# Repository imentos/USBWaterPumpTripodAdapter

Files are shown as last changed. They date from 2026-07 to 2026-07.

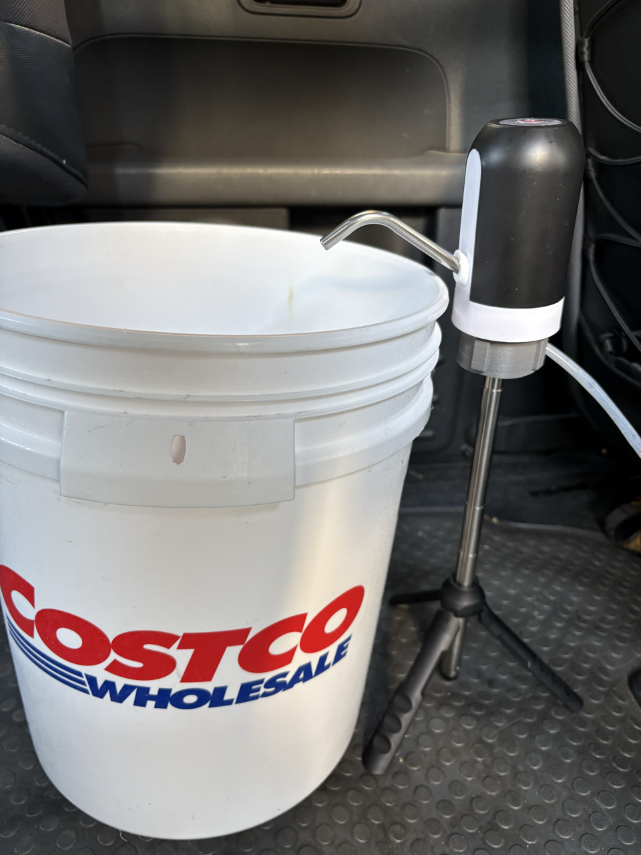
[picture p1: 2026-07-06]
photos/IMG_0860 Large.png

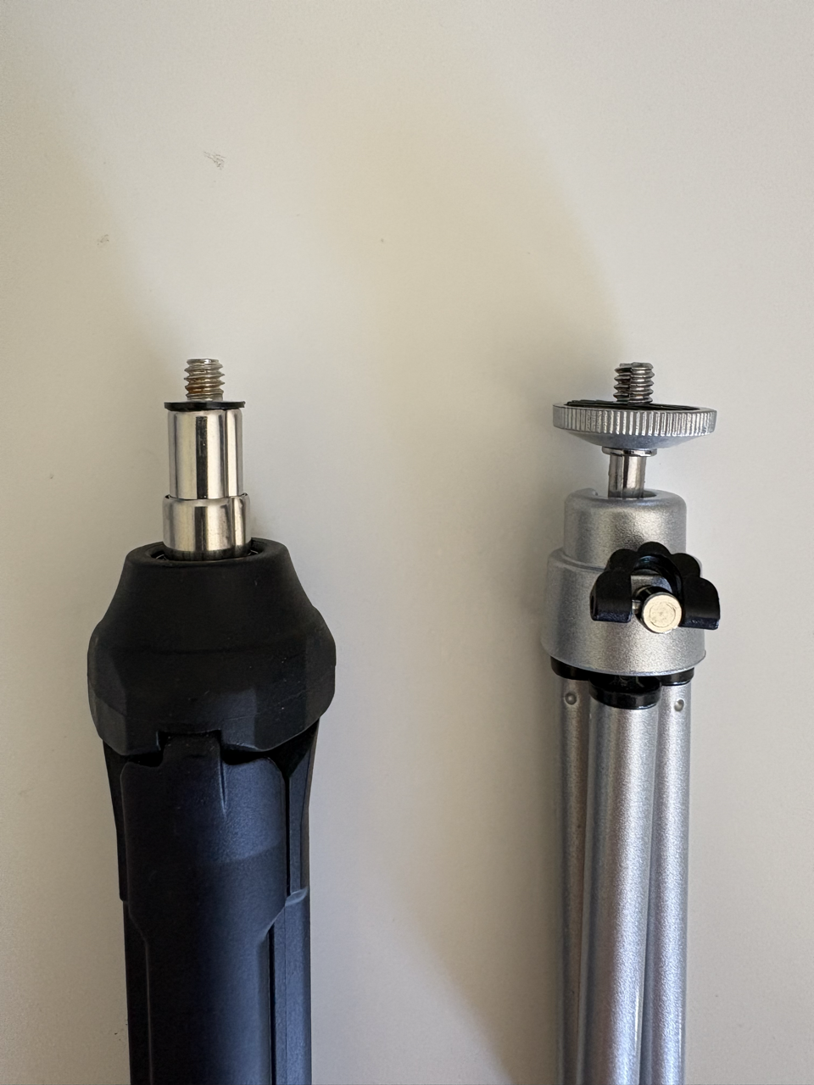
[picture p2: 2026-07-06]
photos/IMG_0835 Large.png

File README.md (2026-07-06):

# USB Water Pump to Tripod Adapter

Three competing FDM-printable concepts for adapting a common USB rechargeable water pump to the photography ecosystem via a standard 1/4"-20 camera mount.

## Shared Assumptions

- Pump bottom has two screws at 32 mm spacing and a center locating cylinder.
- Screw holes are M3 clearance at 3.4 mm.
- Top locating pocket is 18.5 mm diameter by 3.0 mm deep.
- Tripod interface uses a brass 1/4"-20 heat-set insert or metal threaded insert.
- Bottom insert socket assumes 8.2 mm OD by 9.8 mm depth; tune to the actual insert datasheet.
- Print material: PETG or ASA preferred for water resistance; PLA acceptable for fit prototypes.

## Concepts

### Concept A: Low-Profile Round Puck

Smallest and simplest MVP. A 76 mm round adapter with chamfered water-shedding edges, pump screw holes, a top locating pocket, and a reinforced center insert boss.

Best for:
- Fastest iteration
- Easiest print
- Lowest manufacturing complexity

Tradeoff:
- Wider disk than strictly necessary.

### Concept B: Bone Bridge

Material-efficient bridge shape connecting the two pump screw bosses and the center tripod insert boss. Includes side scallops to reduce weight and drying time.

Best for:
- Lower material use
- Distinct product shape
- Keeping strength along the screw-to-insert load path

Tradeoff:
- More exposed edges; less splash shielding than Concept C.

### Concept C: Sealed Tall Boss

Stronger, taller adapter with a pump-foot skirt and shallow groove for silicone or an O-ring style seal. Designed for higher torque from magic arms or cabinet-edge mounts.

Best for:
- Higher load margin
- Better splash resistance
- More confidence with off-axis mounting

Tradeoff:
- Heaviest and slowest to print.

## Print Recommendations

- Orientation: flat on the tripod side, pump side up.
- Layer height: 0.20 mm.
- Perimeters: 4.
- Top/bottom layers: 5.
- Infill: 35% gyroid or cubic.
- Material: PETG for MVP field testing.
- Insert installation: heat-set from bottom after print; use a 1/4"-20 screw as an alignment mandrel while cooling.
- Waterproofing: add thin silicone under pump contact face; avoid sealing screw heads permanently until fit is validated.

## Estimated Print Time and Material

Estimates are based on STL sampled volume, 35% infill, 4 perimeters, 1.24 g/cm3 PETG/PLA density, and a conservative desktop FDM rate. Use a slicer for final numbers.

| Concept | Solid Equivalent | Estimated Printed Mass | Estimated Time |
| --- | ---: | ---: | ---: |
| A Low-Profile Round | 49.3 cm3 | 36-43 g | 2.0-2.7 hr |
| B Bone Bridge | 16.6 cm3 | 14-19 g | 1.1-1.6 hr |
| C Sealed Tall Boss | 68.6 cm3 | 50-60 g | 2.8-3.8 hr |

## Files

- `scad/concept_a_low_profile_round.scad`
- `scad/concept_b_bone_bridge.scad`
- `scad/concept_c_sealed_tall_boss.scad`
- `scad/_pump_adapter_common.scad`
- `stl/*.stl`
- `scripts/generate_stl.py`

## OpenSCAD Export

When OpenSCAD is installed:

```sh
openscad -o stl/concept_a_low_profile_round.stl scad/concept_a_low_profile_round.scad
openscad -o stl/concept_b_bone_bridge.stl scad/concept_b_bone_bridge.scad
openscad -o stl/concept_c_sealed_tall_boss.stl scad/concept_c_sealed_tall_boss.scad
```

The included STLs are generated locally without OpenSCAD and are useful for quick envelope review. They include the main through holes but use faceted sampled geometry. The OpenSCAD files are the production-editable source for smooth final exports.

## V2 Direction: Tall Center-Tripod Side-Hose Base

The latest direction keeps the tripod mount centered. The adapter becomes taller, with the 1/4"-20 brass insert in the bottom center for stability. Instead of a center water pass-through, the water tube enters from the side and turns upward toward the pump intake. This preserves the idea that the pump bottom already matches common 5 gallon / Costco-style bottle mouths, while still allowing the pump to be mounted to a tripod, clamp, or magic arm.

Recommended V2 parts:

- 1/4"-20 UNC brass heat-set insert, about 8-10 mm OD and 8-10 mm long
- M3 stainless screws for the pump's original bottom screw locations
- Silicone hose matched to the pump intake; current CAD side hole is 12.5 mm clearance
- PETG or ASA filament
- Optional silicone gasket or sealant around the hose exit

Estimated V2 print:

| Concept | Solid Equivalent | Estimated Printed Mass | Estimated Time |
| --- | ---: | ---: | ---: |
| D Tall Center-Tripod Side-Hose | 111.2 cm3 | 75-95 g | 4.0-5.5 hr |

New files:

- `scad/concept_d_tall_center_tripod_side_hose.scad`
- `stl/concept_d_tall_center_tripod_side_hose.stl`

## V3 Direction: Friction-Fit Collar, No Pump Screws

The pump bottom is treated as an existing molded bucket-mouth adapter with no required screw fastening. The 3D printed part becomes a slip-on collar: the pump drops into the upper cup, thin silicone/rubber pads take up tolerance, and two optional side clamp screws provide light retention. The centered 1/4"-20 tripod insert remains in the lower body, and the water tube enters from the side.

Critical measurements before printing:

- Pump bottom outside diameter where the collar will grip
- Required insertion depth before the printed part hits the molded pump shape
- Hose outside diameter
- Whether side clamp screws can touch a strong plastic area without damaging the pump

Recommended V3 parts:

- 1/4"-20 UNC brass heat-set insert, about 8-10 mm OD and 8-10 mm long
- Thin silicone/rubber pad sheet, 0.5-1.5 mm thick
- Optional two M4 nylon-tip thumb screws or stainless M4 screws
- Optional M4 heat-set inserts if you want real threaded side clamps
- Silicone hose matched to pump intake; current CAD side hole is 12.5 mm clearance
- PETG or ASA filament

Estimated V3 print:

| Concept | Solid Equivalent | Estimated Printed Mass | Estimated Time |
| --- | ---: | ---: | ---: |
| E Friction-Fit Collar Side-Hose | 122.8 cm3 | 82-105 g | 4.4-6.0 hr |

New files:

- `scad/concept_e_friction_fit_collar_side_hose.scad`
- `stl/concept_e_friction_fit_collar_side_hose.stl`

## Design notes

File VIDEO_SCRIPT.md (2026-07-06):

# Prototype Validation Video Script

Product: tripod adapter for rechargeable USB water pumps.
Audience: car camping, vanlife, RV, portable handwashing, DIY no-plumbing water setups.

## Goal

The first video is not a polished ad. It is a demand validation video. The goal is to get strangers to comment:

- I need this
- Where can I buy it?
- Would this work with my setup?
- I use these pumps for camping/RV/handwashing

## Core Insight

These rechargeable water pumps are normally made to sit on top of a 5-gallon water jug. But many people repurpose them for camping, vanlife, RVs, or DIY handwashing setups. Once the water jug is moved somewhere else, there is no good place to mount the pump.

This adapter lets the pump mount to a normal camera tripod or clamp, using the existing camera-mount ecosystem instead of custom hardware.

## Recommended Voiceover

```text
These rechargeable water pumps are normally made to sit on top of a 5-gallon water jug.

But a lot of people use them for camping, vanlife, or DIY handwashing setups.

The problem is, once you move the water jug somewhere else, there’s no good place to mount the pump.

So I made this adapter that lets the pump attach to a regular camera tripod.

The jug stays on the floor, the pump stays above the basin, and there’s no plumbing or permanent install.

Would you use this for car camping or vanlife?
```

## Shorter Voiceover

```text
These rechargeable water pumps are made to sit on top of a 5-gallon jug.

But for camping or DIY handwashing setups, I wanted the jug on the floor and the pump mounted above a basin.

So I made this adapter that lets the pump attach to a regular camera tripod.

No plumbing, no permanent install.

Would you use this for car camping or vanlife?
```

## Shot List

### 0-4 seconds

Voiceover:

```text
These rechargeable water pumps are normally made to sit on top of a 5-gallon water jug.
```

Visual:

- Show the pump in its normal use position on a water jug or bottle.
- Keep the shot simple and obvious.

On-screen text:

```text
USB water pumps are made for water jugs
```

### 4-8 seconds

Voiceover:

```text
But a lot of people use them for camping, vanlife, or DIY handwashing setups.
```

Visual:

- Show basin, water jug on floor, car camping style setup, or temporary sink area.
- It is okay if this is staged at home.

On-screen text:

```text
But people use them for camping + DIY sinks
```

### 8-12 seconds

Voiceover:

```text
The problem is, once you move the water jug somewhere else, there’s no good place to mount the pump.
```

Visual:

- Show the pump awkwardly sitting, being held, or not having a stable place above the basin.

On-screen text:

```text
Problem: nowhere to mount the pump
```

### 12-17 seconds

Voiceover:

```text
So I made this adapter that lets the pump attach to a regular camera tripod.
```

Visual:

- Show the 3D printed adapter.
- Insert adapter into pump bottom.
- Thread/mount it onto tripod.

On-screen text:

```text
Adapter → regular camera tripod
```

### 17-23 seconds

Voiceover:

```text
The jug stays on the floor, the pump stays above the basin, and there’s no plumbing or permanent install.
```

Visual:

- Hose goes into jug.
- Pump is above basin.
- Press button and show water flowing.

On-screen text:

```text
No plumbing. No permanent install.
```

### 23-26 seconds

Voiceover:

```text
Would you use this for car camping or vanlife?
```

Visual:

- Hold on the complete setup for 2-3 seconds.

On-screen text:

```text
Would you use this?
```

## Filming Notes

- Vertical video.
- 20-30 seconds total.
- You do not need to show your face.
- Film hands, product, water jug, tripod, and water flowing.
- Record voiceover afterward in CapCut or similar.
- Add captions. Many people watch muted.
- Do not make it too polished. A real prototype demo feels more credible for validation.

## Caption For Reddit / Facebook

```text
I made a small adapter for rechargeable USB water pumps.

These pumps are normally made to sit on top of a 5-gallon jug, but I’ve seen a lot of people use them for car camping, vanlife, and DIY handwashing setups. The problem is that once the jug is on the floor or stored away, there is no good place to mount the pump above a basin.

This adapter lets the pump attach to a regular camera tripod or clamp. No plumbing, no permanent install.

Would this be useful for car camping, vanlife, or portable handwashing setups? What would you mount it to?
```

## Short Caption

```text
I made a tripod adapter for rechargeable USB water pumps.

Idea: water jug on the floor, pump mounted above a basin. No plumbing, no permanent install.

Would you use this for car camping or vanlife?
```

## Validation Signals

Good signs:

- People ask where to buy it.
- People ask if it works with their pump.
- People describe their own camping/RV setup.
- People suggest mounting locations like cabinet edge, tripod, magic arm, table clamp, or RV wall.
- People ask for dimensions.

Weak signs:

- Only likes, no comments.
- People say cool but no one asks for one.
- People do not understand what problem it solves.

## Next Step After Posting

If 3 or more strangers ask where to buy it, create an Etsy prototype listing.

If 10 or more people comment with real use cases, make a small first batch.

If people are confused, reshoot the video with a clearer before/after setup.

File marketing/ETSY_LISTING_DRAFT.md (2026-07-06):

# Etsy Listing Draft

## Shop Positioning

Small 3D printed camping water setup accessories. First product: a mount adapter for common USB rechargeable 5-gallon jug water pumps.

Suggested shop names:

- CampTapLab
- TripodTap
- TinyCampTools
- CampFlowLab

Recommended: **CampTapLab**

## Listing Title Options

Best title:

**USB Water Pump Tripod Mount Adapter - 3D Printed 1/4-20 Camera Thread Base for Camping, Vanlife, RV Hand Washing**

Shorter title:

**USB Water Pump Tripod Adapter - 1/4-20 Camera Mount Base for Camping and Vanlife**

Keyword-heavy title:

**5 Gallon USB Water Pump Mount Adapter, Tripod Clamp Camera Thread Base, Camping Sink Vanlife RV Hand Wash Setup**

## Price Test

Recommended first price:

**$21.99 + shipping**

Acceptable test range:

- Low: $17.99
- Recommended: $21.99
- Higher: $24.99

Use made-to-order production. Start with quantity 3-5.

## Main Listing Description

This is a 3D printed adapter/base that lets a common USB rechargeable water pump mount to standard 1/4"-20 camera accessories.

Many rechargeable water pumps are designed to sit directly on top of a 5-gallon water jug. That works when the jug is directly under the pump, but it can be awkward for car camping, vanlife, RV, or portable hand-washing setups where the water container sits on the floor, inside a cabinet, or away from the basin.

This adapter gives the pump a standard camera-mount interface, so it can be used with common mounting accessories such as:

- camera clamps
- small tripods
- magic arms
- articulating arms
- shelf clamps
- RV or camping mounts

The goal is a removable setup without drilling into your cabinet, shelf, or vehicle interior.

## What Is Included

Included:

- 1x 3D printed pump adapter/base
- Installed or included 1/4"-20 threaded insert, depending on production version

Not included:

- USB water pump
- hose
- tripod
- clamp
- magic arm
- water jug
- basin/sink

## Compatibility

Designed for common USB rechargeable water pumps made to fit approximately **2.16 in / 55 mm** 5-gallon bottle openings.

Please check your pump before ordering. This adapter is based on the common jug-top pump style, but pump designs can vary.

## Material / Production

Made to order using FDM 3D printing.

Recommended material:

- PETG for better water resistance and toughness

Prototype note:

Because this is a 3D printed functional part, small layer lines and minor cosmetic variations are normal.

## Suggested Processing Time

**5-7 business days**

Use this wording:

Each adapter is printed to order and checked before shipping.

## Photo Order

1. Full setup photo: water container/hose/pump mounted with clamp or tripod
2. Close-up of pump sitting on adapter
3. Close-up of adapter connected to clamp/tripod/camera mount
4. Adapter by itself
5. Bottom view showing 1/4"-20 mount area
6. Short demo video showing water dispensing

## Etsy Tags

Etsy allows 13 tags. Suggested tags:

- camping water pump
- water pump adapter
- vanlife sink
- car camping gear
- rv water pump
- camping sink
- 5 gallon pump
- tripod adapter
- camera mount
- hand wash station
- overlanding gear
- 3d printed gear
- portable sink

## Category Ideas

Try one of these depending on Etsy category options:

- Sports & Outdoor Recreation > Camping
- Home & Living > Storage & Organization > Garage Storage
- Electronics & Accessories > Gadgets
- Craft Supplies & Tools > Tools

Best fit is likely camping/outdoor accessory if available.

## FAQ

### Does this include the pump?

No. This listing is for the adapter/base only. The USB water pump, hose, clamp, tripod, magic arm, water jug, and basin are not included.

### What pump does it fit?

It is designed for common USB rechargeable jug-top pumps made for approximately 2.16 in / 55 mm 5-gallon bottle openings. Please check your pump before ordering.

### Why use this instead of putting the pump on a counter?

These pumps are designed to sit on a water jug neck, not on a flat counter or shelf. This adapter gives the pump a stable removable mount when the water jug is on the floor, inside a cabinet, or away from the basin.

### Can I use it with a clamp instead of a tripod?

Yes, as long as the clamp uses a standard 1/4"-20 camera screw. Many camera clamps, magic arms, tripods, and small mounts use this standard.

### Is it waterproof?

It is intended for water-adjacent camping use, but it is not a sealed plumbing part. Avoid submerging the adapter or using it as a pressure fitting.

## First Facebook Reply When Etsy Is Ready

Thanks for the feedback. I made a small first-batch listing for the physical adapter/base here: [Etsy link]

It is made to order and designed for the common ~55 mm jug-top USB pump style. Pump/clamp/tripod not included.

## Important Listing Disclaimer

This is an independent 3D printed accessory. It is not affiliated with or endorsed by any water pump, camera mount, tripod, RV, or vehicle brand.

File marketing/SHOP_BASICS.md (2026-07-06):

# Shop Basics

## Shop Name

Recommended shop name:

**CampTapLab**

Backup names:

- TrailTapLab
- CampFlowLab
- TinyCampTools
- VanTapLab
- NomadTapTools
- TripodTap

## Brand Direction

Small practical accessories for camping water setups, vanlife, RVs, car camping, and portable hand-washing.

Keep the brand broad enough for future products, not only one tripod adapter.

## First Product

**USB Water Pump Tripod Mount Adapter**

A 3D printed adapter/base that lets common jug-top USB rechargeable water pumps mount to standard 1/4"-20 camera accessories.

## Core Customer Problem

Common USB rechargeable water pumps are designed to sit directly on top of a 5-gallon jug.

That works when the jug is directly below the pump, but it becomes awkward when the water container is:

- on the floor
- inside a cabinet
- in a cargo area
- away from the basin
- used in a car camping / vanlife / RV setup

The pump needs a stable mount without drilling into shelves, cabinets, or vehicle interiors.

## Core Product Promise

Turn a common jug-top USB water pump into a camera-mount compatible pump.

USB water pump -> adapter/base -> standard 1/4"-20 camera mount -> clamp / tripod / magic arm / shelf mount

## Main Selling Points

- No drilling required
- Uses standard 1/4"-20 camera mount ecosystem
- Works with clamps, tripods, magic arms, and other camera accessories
- Useful for car camping, vanlife, RVs, and portable hand-washing setups
- Made to order
- Compact and simple

## What To Sell First

Sell the **physical adapter/base**, not the STL file.

Do not sell the pump, clamp, tripod, hose, jug, or basin at first.

## Listing Basics

Product type: Physical item

Production method: 3D printed, made to order

Starting quantity: 3-5

Processing time: 5-7 business days

Recommended first price: $21.99 + shipping

Acceptable price test range:

- $17.99: easier first sales, lower margin
- $21.99: recommended first test
- $24.99: good if photos/video are strong

## Compatibility Language

Use this wording:

Designed for common USB rechargeable water pumps made to fit approximately **2.16 in / 55 mm** 5-gallon bottle openings.

Please check your pump before ordering. This adapter is based on the common 55 mm jug-top pump style, but pump designs can vary.

## Important Disclaimer

Pump, clamp, tripod, hose, water jug, and basin are not included.

This is an independent 3D printed accessory. It is not affiliated with or endorsed by any water pump, camera mount, tripod, RV, vehicle, or camping brand.

## Short Product Description

A 3D printed adapter/base that lets common USB rechargeable 5-gallon water pumps mount to standard 1/4"-20 camera accessories such as clamps, tripods, and magic arms.

Designed for car camping, vanlife, RV, and portable hand-washing setups where the water jug sits on the floor, inside a cabinet, or away from the basin.

## Etsy Title

USB Water Pump Tripod Mount Adapter - 3D Printed 1/4-20 Camera Thread Base for Camping, Vanlife, RV Hand Washing

## Etsy Tags

- camping water pump
- water pump adapter
- vanlife sink
- car camping gear
- rv water pump
- camping sink
- 5 gallon pump
- tripod adapter
- camera mount
- hand wash station
- overlanding gear
- 3d printed gear
- portable sink

## Photo Order

1. Full setup photo showing pump mounted and water setup context
2. Demo image or video showing water dispensing
3. Close-up of pump on adapter
4. Close-up of adapter connected to clamp/tripod/camera mount
5. Adapter by itself
6. Bottom view showing 1/4"-20 mount area

## Facebook Positioning

Do not post like an ad first. Post as a prototype / DIY setup question.

Good wording:

I made a small 3D printed prototype for my car camping water setup and wanted feedback.

These USB rechargeable water pumps are usually made to sit directly on top of a 5-gallon jug, but in a car camping setup I often want the water jug on the floor / cargo area and the pump above a basin.

So I made an adapter that lets the pump mount to standard 1/4"-20 camera accessories like clamps, tripods, and magic arms.

Not selling anything in this post -- just testing the idea.

Would this be useful for car camping, or is it too niche?

## Reply When Someone Asks If You Are Selling

Right now I’m testing the prototype and trying to understand what setup people actually need.

The part I made is the adapter/base that fits the pump and gives it a standard 1/4"-20 camera mount. Then people can use whatever mount works for their setup: clamp, tripod, magic arm, etc.

If there’s enough interest, I may make a small batch of the printed adapter/base first.

## Reply When Etsy Listing Is Ready

Thanks for the feedback. I made a small first-batch listing for the physical adapter/base here: [Etsy link]

It is made to order and designed for the common ~55 mm jug-top USB pump style. Pump, clamp, tripod, hose, jug, and basin are not included.

## Handling Negative Feedback

Some people already have sink-style pumps or simpler water jug setups. They are not the target customer.

Good reply:

That makes sense. If someone already has the faucet-style pump made for a sink setup, that’s definitely the cleaner solution.

I’m mostly testing this for people who already have the jug-top pump and want a removable way to mount it without drilling or changing their setup.

Appreciate the perspective -- it helps me understand where this does and doesn’t make sense.

## Product Lessons From Facebook Comments

Useful validation signals:

- People use the same pump for car camping / van camping
- People need shelf, cabinet, clamp, or swing-out basin mounting
- People already DIY magnetic bases or other mounts
- People asked whether the adapter/base is for sale

V2 ideas:

- Magnetic base accessory
- Side 1/4"-20 threaded mount
- More compact version
- Shelf/cabinet clamp bundle recommendation
- Pump compatibility variants

Do not redesign V1 immediately. First sell/test the simple 1/4"-20 bottom mount version.

## Current Final Model Files

Final STL:

`stl/final_walmart_plug_55_0mm_center_mark_adapter_openscad_fn256.stl`

Final SCAD:

`scad/final_walmart_plug_55_0mm_center_mark_adapter.scad`

## Next Steps

1. Reserve shop name.
2. Create one Etsy listing.
3. Use made-to-order quantity 3-5.
4. Upload photos and demo video.
5. Do not run Etsy ads at first.
6. Share Etsy link only when people ask where to buy.
7. Track questions and compatibility issues from first buyers.

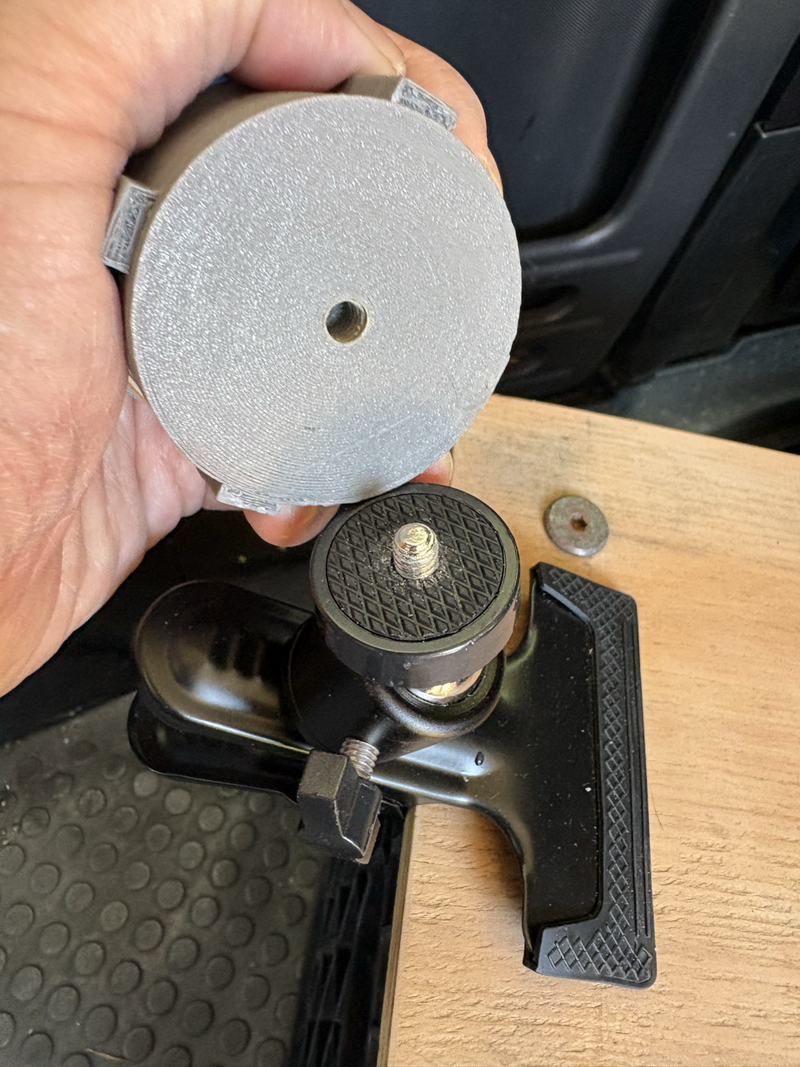
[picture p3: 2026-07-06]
photos/IMG_0834 Large.png

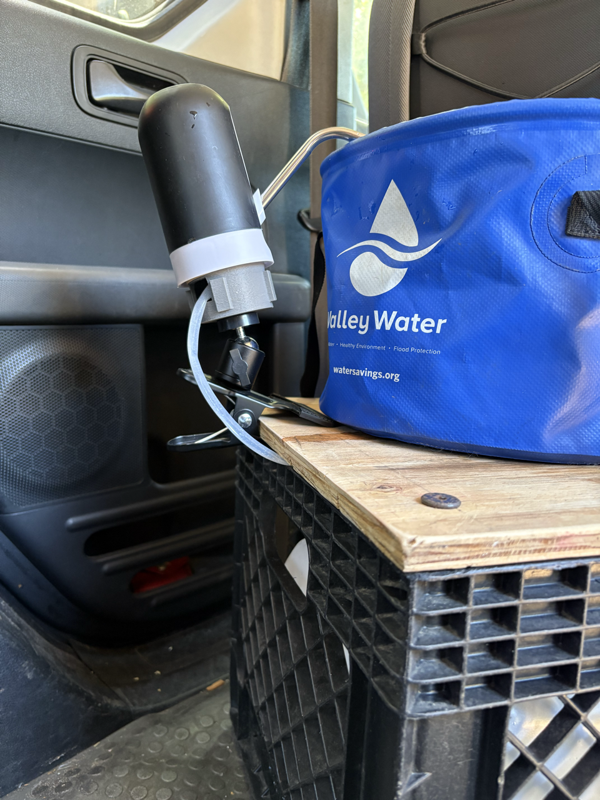
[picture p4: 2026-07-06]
photos/IMG_0832 Large.png

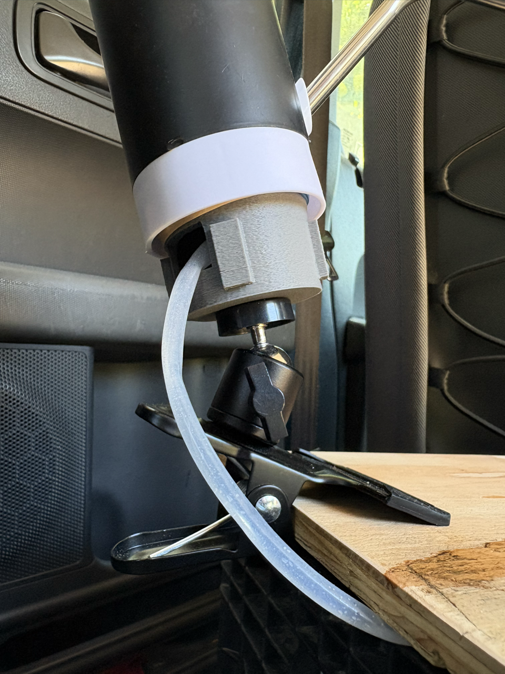
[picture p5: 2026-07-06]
photos/IMG_0833 Large.png

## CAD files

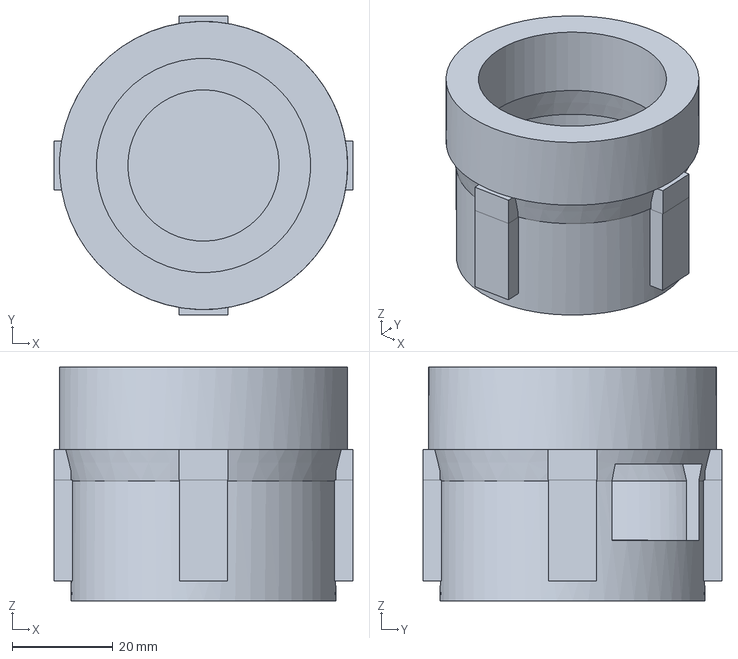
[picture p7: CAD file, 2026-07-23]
FreeCAD/usb adapter.FCStd
59.3 x 59.3 x 46.4 mm

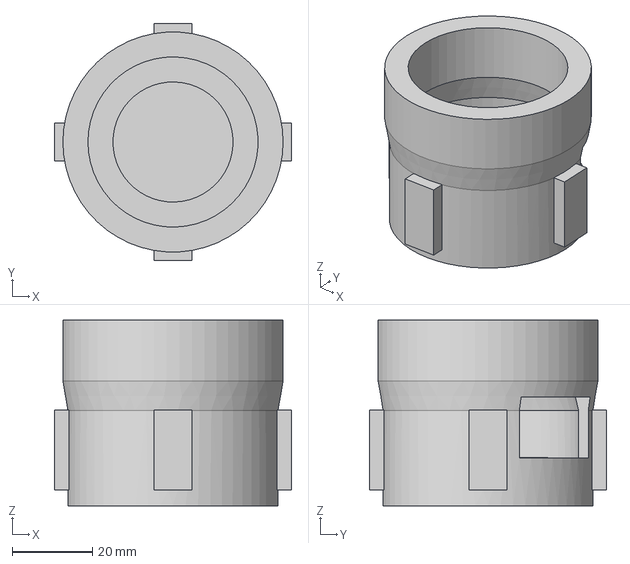
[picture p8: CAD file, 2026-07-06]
Tripod Adapter from Tyler (FB)/Tripod Adapter.step
59.2 x 59.2 x 46.4 mm

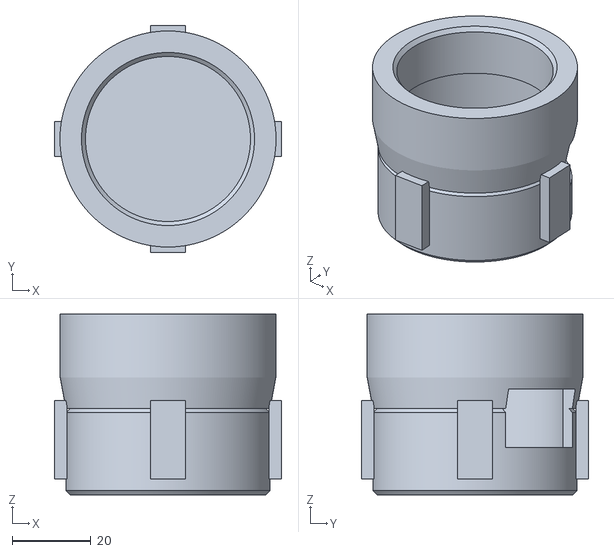
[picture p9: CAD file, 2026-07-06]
stl/final_walmart_plug_55_0mm_center_mark_adapter_openscad_fn256.stl
57.8 x 57.8 x 46.0

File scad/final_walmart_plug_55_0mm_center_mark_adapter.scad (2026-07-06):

$fn = 256;


// FINAL Walmart plug version.
// Adapter upper feature mimics a 5.5 cm water-jar neck and inserts into the pump.
// Only the upper fit changed from the previous thin-wall version. Lower base, side
// exit, four grips, and bottom center mark are retained.

plug_od = 55.0;          // Walmart jar spec target; all dimensions are in mm.
plug_h = 16;
plug_wall = 3.0;
plug_inner_d = 42;       // Open center so hose can pass through.

base_od = 52;
base_wall = 3.0;
base_id = base_od - 2 * base_wall;
base_h = 30;
shoulder_h = 8;
insert_boss_d = 30;
insert_boss_h = 12;
side_opening_w = 24;
side_opening_bottom_z = insert_boss_h;
side_opening_top_z = base_h - 3;
side_opening_h = side_opening_top_z - side_opening_bottom_z;
side_opening_z = (side_opening_top_z + side_opening_bottom_z) / 2;
side_opening_angle = 45;
grip_column_w = 9;
grip_column_depth = 3.2;
grip_column_z0 = 4;
grip_column_h = 20;
lip_chamfer = 1.2;
center_mark_d = 3.0;
center_mark_depth = 1.0;


module water_shedding_chamfer(d, h, chamfer=1.2) {
  cylinder(d1 = d - 2 * chamfer, d2 = d, h = chamfer);
  translate([0, 0, chamfer])
    cylinder(d = d, h = h - 2 * chamfer);
  translate([0, 0, h - chamfer])
    cylinder(d1 = d, d2 = d - 2 * chamfer, h = chamfer);
}

module grip_column(angle) {
  rotate([0, 0, angle])
    translate([base_od / 2 - 0.3, -grip_column_w / 2, grip_column_z0])
      cube([grip_column_depth, grip_column_w, grip_column_h]);
}

module four_grip_columns() {
  for (a = [0, 90, 180, 270])
    grip_column(a);
}

module side_opening() {
  rotate([0, 0, side_opening_angle])
    translate([0, -side_opening_w / 2, side_opening_z - side_opening_h / 2])
      cube([base_od / 2 + grip_column_depth + 8, side_opening_w, side_opening_h]);
}

difference() {
  union() {
    water_shedding_chamfer(base_od, base_h - shoulder_h, 1.1);

    // Printable shoulder from lower body to smaller plug.
    translate([0, 0, base_h - shoulder_h])
      cylinder(d1 = base_od, d2 = plug_od, h = shoulder_h + 0.1);

    // Independent solid boss for heat-set insert.
    cylinder(d = insert_boss_d, h = insert_boss_h);

    // Upper plug that inserts into pump bottom.
    translate([0, 0, base_h - 0.1])
      cylinder(d = plug_od, h = plug_h + 0.1);

    four_grip_columns();
  }

  // Hollow lower shell.
  translate([0, 0, 1.2])
    cylinder(d = base_id, h = base_h - shoulder_h + 0.4);

  // Open center through plug and chamber for hose passage.
  translate([0, 0, insert_boss_h])
    cylinder(d = base_id, h = base_h - insert_boss_h + 2);

  translate([0, 0, base_h - 0.4])
    cylinder(d = plug_inner_d, h = plug_h + 1.5);

  // Lead-in chamfer on plug top.
  translate([0, 0, base_h + plug_h - lip_chamfer])
    cylinder(d1 = plug_inner_d, d2 = plug_inner_d + 2 * lip_chamfer, h = lip_chamfer + 0.2);

  // Side hose exit.
  side_opening();

  // Tiny center mark for heat-set insert alignment.
  translate([0, 0, -0.2])
    cylinder(d = center_mark_d, h = center_mark_depth + 0.2);
}

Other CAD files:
stl/Tripod_Adapter_V3_57_15mm_Shoulder_Pillars.stl
Tyler v2/Tripod Adapter V2.step
FreeCAD/adapter fix.FCStd
stl/tripod-adapter-v2-57_15mm-top.stl
Tyler v2/Tripod Adapter V3 57.15mm Shoulder Pillars.step
Tripod Adapter from Tyler (FB)/Tripod Adapter.stl
Tripod Adapter from Tyler (FB)/Tripod adapter.3mf
Tyler v2/Tripod Adapter V2.3mf
Tyler v2/Tripod Adapter V2.stl
Tyler v2/Tripod Adapter V3 57.15mm Shoulder Pillars.stl

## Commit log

2026-07-06 Initial project commit
    [Tripod Adapter.step, Tripod Adapter.stl, Tripod adapter.3mf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]
2026-07-22 Add 57.15mm top adapter STL
    [tripod-adapter-v2-57_15mm-top.stl]
2026-07-23 Add FreeCAD V3 shoulder pillar adapter files
    [Tripod Adapter V2.3mf, Tripod Adapter V2.step, Tripod Adapter V2.stl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]
2026-10-28 Add V8 wood screw-down base
2026-10-30 Optimize V8 magnetic base for faster printing
